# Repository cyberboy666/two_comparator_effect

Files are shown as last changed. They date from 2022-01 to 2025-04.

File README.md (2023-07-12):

# two_comparator_effect
### analog video posterisation effect - adapted from a rob schafer design



- this circuit is distributed by __UNDERSCORES__ - _an open video hardware label_ : it is available to purchase - as a pcb, kit or assembled unit - at [underscores.shop](https://underscores.shop/two_comparator_effect/)
- the schematic for the circuit can be found [here](/hardware/schematic.pdf)
- the pcb gerber files for the lastest version can be found [here](/hardware/gerber_latest.zip)
- interactive BOM is [here](https://htmlpreview.github.io/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)
- consider [donating](https://opencollective.com/underscores) to the underscores project to help us continue creating for the commons

## demo video

(https://videos.scanlines.xyz/w/t1Ht54aVoeiCa2ZGb4LRMV)

## background

<details>
<summary>background</summary>

Rob Schafer designed the original version of this circuit in his excellent [whiteboard schoolhouse](https://www.youtube.com/watch?v=9HMj0sfPa0w&list=PLoNU5z_Oqfgj1xfSBMg6XaIhAX2ftyfkN) youtube series.

It was updated and adapted to pcb by cyberboy666 as open-source hardware with help from the [scanlines community](https://scanlines.xyz/t/whiteboard-schoolhouse-companion-circuits/127/23) – this version debuted as a mail-in soldering workshop for [VIDICON_2020](https://vidicon.org/)







robs original circuit, the schematic and effect shown here 

</details>
  
# documentation

this project is fully _open-source hardware_ - all the files required to build it are included in this repo for free. if you have the time and/or skill you can contribute back by collaborating on / testing new designs, improving these docs, making demo videos/other creative content etc. you can also support the project financially by [donating](https://opencollective.com/underscores) directing, or purchasing through the [web shop](https://underscores.shop).

depending on whether you are going fully diy or buying an assembled and tested unit, some of the following guides will be relavent to you. the flow would be:

## ordering parts

<details><summary><b>parts sourcing guide (w/ notes on pcb fabracation )</b> - start here if you are building fully from scatch or have purchased a pcb</summary>

i try to source all the parts i can from either:
- [tayda](https://www.taydaelectronics.com/) ; cheaper for common parts like resistors etc, also good for mechanical parts like switches and buttons
- [mouser](https://www.mouser.de/) ; has lots more options, speciality video ic's, can sometimes cost more (free shipping on orders over 50euros)
- other ; ocationally there will be parts which will need to be sourced elsewhere - usaully either aliexpress, ebay or amazon etc...

take a look at the [full_bom](/hardware/bom/full_bom.csv) for this project to see where i am sourcing each part from

## import into tayda

- go to the [tayda quick order](https://www.taydaelectronics.com/quick-order/) and in bottom corner choose _add from file_
- select the file [tayda_bom.csv](./hardware/bom/tayda_bom.csv) in the BOM folder (you will have to download it first or clone this repo)
- after importing select _add to cart_
- __NOTE:__ the minimum value for resistors is 10, so you may need to modify these values to add to cart (or if they are already modified here you will need to see the  full_bom for actual part QTY) 

- OPTIONAL: it is a good idea to add some dip-ic sockets and 2.54pin headers/sockets to your tayda order if you dont have them around already
  
## import into mouser

- go to [mouser bom tool](https://nz.mouser.com/Bom/) and click _upload spreadsheet_
- select the file [mouser_bom.csv](./hardware/bom/mouser_bom.csv) in this folder (you will have to download it first or clone this repo), then _upload my spreadsheet_ and _next_
- ensure that __Mouser Part Number__ is selected in the dropdown above the first row, then _next_, _process_
- if everything looks correct can now put _add to basket_

# ordering pcbs

you can support this project by buying individual pcbs from the [shop](https://underscores.shop). if you would rather have pcbs fabricated from gerbers directly the file you need is [here](/hardware/gerber_latest.zip)

- i get my pcbs fabricated from [jlcpcb](https://cart.jlcpcb.com/quote) - 5 is the minumum order per design
- upload the zip file with the `add gerber file` button
- the default settings are mostly fine - set the __PCB Qty__ and __PCB Color__ settings (you can check that the file looks correct with pcb veiwer)
- it may be best to combine orders with other pcbs you want to have fab'd since the shipping can cost more than the items - also orginising group buys is a good way to distribute the extra pcbs /costs 
  
i often use jlcpcb because they are reliable, cheap and give you an option of colours. remember though that the cheapest Chinese fab houses are not always the most ethical or environmently friendly - if you can afford it consider supporting local companies. 

  </details>
  
## assembly guide
  
<details><summary><b>assembly guide</b> - start here if you have purchased a diy kit</summary>

## interactive BOM for build guiding

follow this link to view the [interactive BOM](https://htmlpreview.github.io/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)

## general solder advice

- remember to heat pad first (2-3seconds), then add solder, then continue to heat (1-2seconds)

- Checkout the web-comic [soldering is easy](https://mightyohm.com/files/soldercomic/FullSolderComic_EN.pdf) for more soldering advice

## general order of assembly

- in general while assembling i start placing resistors and capacitors first. placing 5 - 10 components at a time and then flipping the board to solder them and trim the legs etc.
- next i would do diodes, transistors and ic's - taking care that these are placed in the right direction (using a ic socket can be useful)
- finally i place the interface parts - rca jacks, power jack, pots and switches - make sure these have lots of solder on for structural stablity

## specific assembly advice

- start with the resistors, taking care place the correct value in the correct footprint (if you are unsure of the value can use an online resistor calculator ) , direction does not matter. Place a few resistors in (as many as you are comfortable with) then solder and trim legs

- next lets do capacitors: 0.1u will say 104, while 1uf will say 105 on them - place them all and solder and trim.

- now lets place diodes and transistors. take note of the direction on the diode - black bar on component matching black bar on footprint. Transistor values are printed on thembe sure not to mix them up ! be careful when soldering the to92 parts the pads are very close - this is the hardest part - i soldered the outer legs first, trimmed these and then soldered inner.

- now lets do the ic/socket -> make sure the direction is correct! place in and fold two corner pins to hold in place, then solder all pins. you can place the ic in now too.

- finally lets place the control parts, starting with the power jack (can use something under the board to balance it while you solder), next place the rca jacks and pots. be generous with the solder here -> this is to strengthen the mechanical connections as well as making electrical ones
  
</details>

## operating guide
  
<details><summary><b>operating guide</b> - start here if you have purchased an assembled unit</summary>

  

- To set up using the circuit plug an active video source into composite video input and a display into composite video output (flipping the bypass switch should show the raw video source passing through the circuit to the display)

- Next plug in a 5v center-positive power supply into the 2.1mm barrel jack connector – I like to use a usb wall charger for this

- switch the bypass again to activate the circuit - Adjusting the level knobs should change the resulting image – the thresholds control which brightness levels result in white black or gray regions.

- Depending on your display setting either or both knobs fully counter-clockwise can result in glitchy effects, colour bleeds and sync drops

</details>

### more info

<details><summary><b>how the circuit works</b></summary>
  
Watch the youtube videos [Lesson 1 – Comparators](https://www.youtube.com/watch?v=ml8xnRFdcHY) and [Lesson 2 – Clamping](https://www.youtube.com/watch?v=FymrxKLHy6c) by Rob Schafer for full explanation. See full schematics on the project page.
  
This circuit works by using multiple stages of an LM339 - Quad Differential Comparator ic. 


  
A comparator stage compares the two voltages on its input (plus and minus) and outputs high if plus > minus, low if plus < minus. Since we power the ic with +5v, in this case high is an output of +5v and low is an output of 0v
                                                                                                                                 
comparator plus input is connected to the analog video signal (where higher voltage corresponds to a brighter image)


  
The minus input is connected to a reference voltage which can be set by turning a potentiometer. varying the pot adjusts the resistance in this voltage divider configuration which in turn varies the voltage supplied as reference
                                                                                                                                 

The result of this effect is an image that is all white for regions of the original image above a given brightness threshold level, and all black for the regions below this level. Changing this threshold changes which parts of the image are set to black vs white.

Here is a scoped example of an original signal (top) with threshold and the resulting signal (bottom)


                                                                                                                                 
Before reaching the comparators, the incoming video signal needs to be SOFT CLAMPED – this is done using a capacitor, diode and a 1.25v rail that was obtained with a LM317 voltage regulator.



A composite video signal tends to squash up when the image is bright and spread out when it is darker.

For the comparator reference voltages to be consistence we need to correct for this behavior by clamping the signal to a fixed voltage level
                                                                                                                                 


A third comparator stage with a fixed reference voltage is used to ‘pick off’ the sync pulse of the original signal.

The output from these three comparator stages are scaled and combined to create a new composite video signal with the desired effect
                                                                                                                                 


Composite video encodes color as a sub-carrier frequency over the signal.

This circuit is designed for use with gray-scale video input where no sub-carrier is present, although it does still work with color input – usually ignoring the _sub-carrier_, although occasionally there are some artifacts generated by this. This is more common with NTSC than with PAL

glitch artifacts are also created when the comparator thresholds are set below the _black-level_ of the video signal, causing the signal to lose sync. 
                                                                                                                             
</details>

<details><summary><b>contributing guide</b></summary>
  
if you would like to contribute back to these projects in some way but dont know how the best thing (for now) would be to reach out to me directly ( tim@cyberboy666.com or @cyberboy666 on scanlines forum) - i will be happy to help
  
</details>

## credits & more info

This circuit is distributed through UNDERSCORES – open video hardware label – visit [underscores.shop](https://underscores.shop) for more info

The pcb was designed using KICAD , the booklet was created in LibreOffice Draw

Everything from gerbers, cad files, panels and documentation is freely available online and distributed under CC-BY-SA / open-source licenses – help us contribute to the commons !

Ask any questions or start discussions related to this project on the [scanlines.xyz](https://scanlines.xyz) forum – an online community space dedicated to diy av / electronic media art

You can contact me directly at tim (at) cyberboy666 (dot) com 
Please get in touch if you are interested in hosting a workshop !



Thanks to Rob Schafer for sharing your designs and knowledge. to Bastien Lavaud for circuit advice, always. To Guergana Tzatchkova for booklet design inspiration. To Ben Caldwell for project advice. To everyone who has or will contribute ♥♥♥

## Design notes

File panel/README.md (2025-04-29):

# enclosure guide

we now offer two kinds of enclosures for this project:

- __stand-alone enclosure__ - made from a front and back panel, plus screws and standoffs



- __eurorack enclosure__ - made from just a front panel, plus screws and standoffs to mount in a eurorack case



you can support these projects by getting enclosure kits directly through [underscores.shop](https://underscores.shop) - [standalone](https://underscores.shop/product/standalone-enclosure-kit-for-two_comparator_effect/) and [eurorack](https://underscores.shop/product/eurorack-kit-for-two_comparator_effect/) - _if ordered with an assembled unit we will also assemble the enclosure for you also_

# diy part sourcing

## panel fabrication

included in this repo are the cad files needed to create your own panels. they are designed in kicads pcbnew - so open the `.kicad_pcb` file to edit them directly. 

you can also use the exported `gerber` files (here they are combined in `.zip`) to get panels fabricated in __fr4__ at a pcb house like the ones we sell. (these usually have a minimum order of 5 or 10)  

another option for diy fabrication is using a lasercutter to cut the panels in wood or acrylic. this is what i do when prototyping panels so you should find some exports in `svg` or `dxf` that are laser ready. _note that the `edgecut` layer is for cutting out and the `silkscreen` layer is for the panel markings. you may need to edit these files or export directly from pcbnew to suit the cutter you are using_

it would also be possible to import these panel files into a sketch in 3d cad program like __freecad__ to create a 3d enclosure for 3d printing... however this is not something i have files prepared for

## 3d printing

i use some custom modelled switch and pot caps for my enclosure kits. you can print these yourself or upload them to a 3d printing fabrication service.

## enclosure kit BOM

things like screws and standoffs can be sourced from lots of places. i will link my source as an example although these links often expire. you could even 3d print your own standoffs from the _id/od_ and length (inner diameter 3.2mm, outer diameter 5mm)

### standalone enclosure

item | source
--- | ---
Front panel | [two_comparator_effect_v0_3_1_default_panel_mk_ii.zip](https://github.com/cyberboy666/two_comparator_effect/blob/main/panel/default_panel/two_comparator_effect_v0_3_1_default_panel_mk_ii.zip) gerber
Back panel | [back_panel.zip](https://github.com/cyberboy666/two_comparator_effect/blob/main/panel/back_panel/back_panel.zip)
Rubber feet x4 | [aliexpress](https://www.aliexpress.com/item/1005005287385986.html?pdp_ext_f=%7B%22sku_id%22:%2212000032498489269%22%7D)
Pot cap x2 | 3d printed from [stl file](https://github.com/cyberboy666/enclosure_kit_commons/blob/main/cap_pot_6mm_shaft/cap_pot_star_single_r2.8.stl)
M3-25mm screw x4 | [aliexpress](https://www.aliexpress.com/item/1005002364189187.html?pdp_ext_f=%7B%22sku_id%22:%2212000020354274907%22%7D)
M3 nut x4 | [aliexpress](https://www.aliexpress.com/item/1005007502691265.html?pdp_ext_f=%7B"sku_id":"12000041089836836"%7D)
m3-12mm standoff x4 (front) | [aliexpress](https://www.aliexpress.com/item/1005003086579258.html?pdp_ext_f=%7B"sku_id":"12000023995222163"%7D)
m3-5mm standoff x4 (back) | [aliexpress](https://www.aliexpress.com/item/1005003086579258.html?pdp_ext_f=%7B"sku_id":"12000023995222156"%7D)

### eurorack enclosure

item | source
--- | ---
Eurorack front panel | [two_comparator_effect_panel_v0_3_1_eurorack_panel_mk_ii.zip](https://github.com/cyberboy666/two_comparator_effect/blob/main/panel/eurorack_panel/two_comparator_effect_panel_v0_3_1_eurorack_panel_mk_ii.zip)
Eurorack 16pin power converter | [eurorack_to_usb_passive_mk_i.zip](https://github.com/cyberboy666/enclosure_kit_commons/blob/main/eurorack_power-adapters/eurorack_to_usb_passive/eurorack_to_usb_passive_mk_i.zip) gerber
Vertical barrel jack | [tayda](https://www.taydaelectronics.com/dc-power-jack-2-1mm-round-type-panel-mount-1.html)
Pot cap x2 | 3d printed from [stl file](https://github.com/cyberboy666/enclosure_kit_commons/blob/main/cap_pot_6mm_shaft/cap_pot_star_single_r2.8.stl)
M3-25mm screw x4 | [aliexpress](https://www.aliexpress.com/item/1005002364189187.html?pdp_ext_f=%7B%22sku_id%22:%2212000020354274907%22%7D)
M3 nut x4 | [aliexpress](https://www.aliexpress.com/item/1005007502691265.html?pdp_ext_f=%7B"sku_id":"12000041089836836"%7D)
m3-12mm standoff x4 (front) | [aliexpress](https://www.aliexpress.com/item/1005003086579258.html?pdp_ext_f=%7B"sku_id":"12000023995222163"%7D)
m3-8mm screw x4 | [aliexpress](https://www.aliexpress.com/item/1005002364189187.html?pdp_ext_f=%7B%22sku_id%22:%2212000020354274900%22%7D)

## eurorack power jack placement

many underscores circuits take 5v from a [horizontal mounted dc barrel jack](https://www.taydaelectronics.com/dc-power-jack-2-1mm-barrel-type-pcb-mount.html) which is good for standalone circuits powered from the side. however for eurorack mounted circuits it can be easier to plug in power from behind. in this case we can use a [vertical dc socket](https://www.taydaelectronics.com/dc-power-jack-2-1mm-round-type-panel-mount-1.html) instead. for these sockets the longer pin is GND which goes closest to the edge of pcb.

Screenshot from 2025-04-29 11-19-55



## enclosure assembling

these enclosures are assemlbed by creating a stack of front-panel -> circuit -> back-panel using the screws and standoffs. where the front standoffs go between front panel and pcb and back standoff go between back panel and pcb. the m3 hex holds it together from the bottom.

i find it easiest to hold circuit on its side and work around one screw at a time:

- first place the front standoff between front panel and pcb
- then put the screw through holding them together
- next place back standoff on screw followed by back panel and hex
- then repeat for other 3 corners

tweezers can be helpful to pick and place the standoffs and also to tighten the m3 hexs

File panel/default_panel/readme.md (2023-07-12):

# two_comparator_effect default_panel notes

- the mounting holes fit m3 screws
- the front_panel mounts to pcb with 12mm standoffs
- 25mm screws will fit front_panel, pcb and back_plate
- the default potentiometers in underscores BOMs have 12mm shaft lengths - consider replacing these with >17mm shaft length alternatives if you plan to use it with a panel

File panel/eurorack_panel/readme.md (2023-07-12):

# two_comparator_effect eurorack_panel notes

- the mounting holes fit m3 screws
- the front_panel mounts to pcb with 12mm standoffs
- this circuit is powered by 5v on 2.1_barrel_jack - a [vertical jack](https://www.taydaelectronics.com/dc-power-jack-2-1mm-round-type-panel-mount-1.html) soldered to bottom of pcb will allow powering from within eurorack case
- this panel is 7HP
- the default potentiometers in underscores BOMs have 12mm shaft lengths - consider replacing these with >17mm shaft length alternatives if you plan to use it with a panel

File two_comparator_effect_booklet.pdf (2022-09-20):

### cyberboy666 & underscores.shop present a circuit adapted from rob schafer design

# two_comparator_effect

## diy analog video posterization

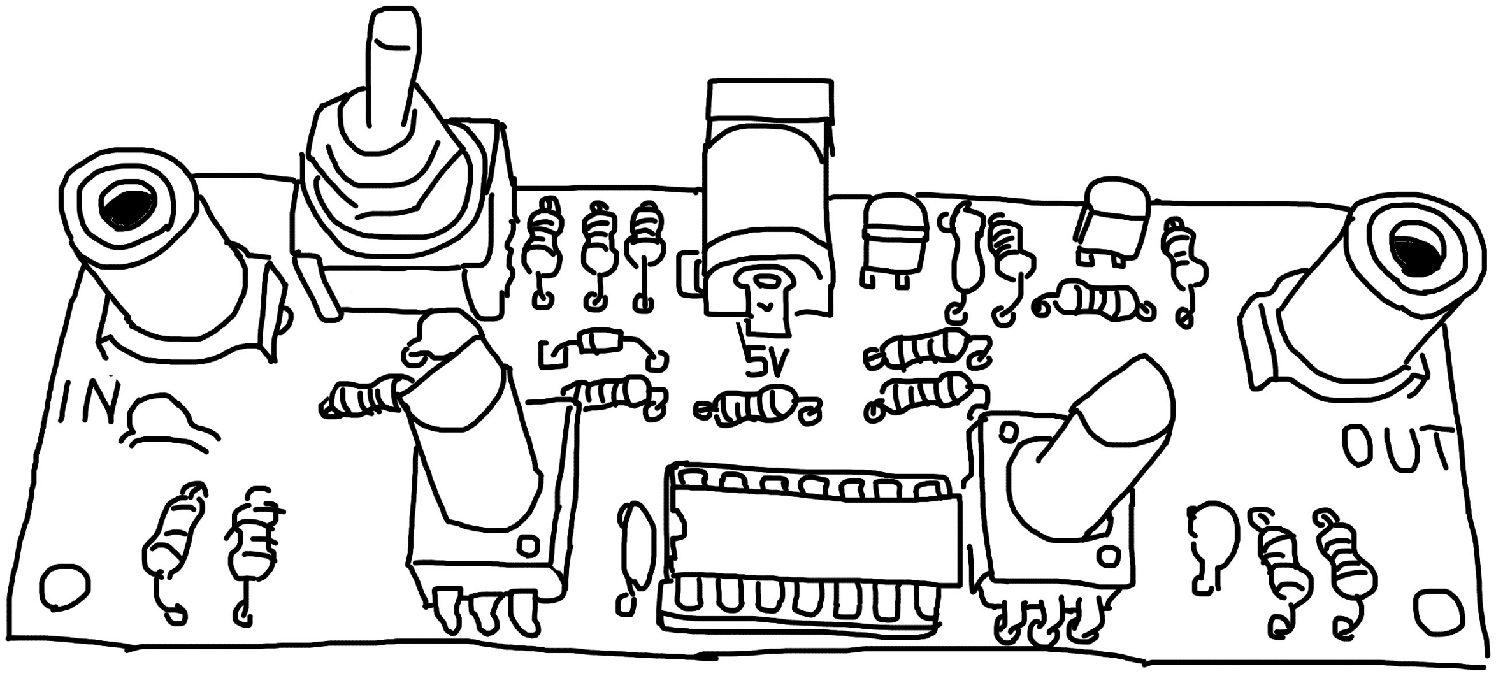
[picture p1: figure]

## instruction manual and build guide

## V0_3_1

View this project online at underscores.shop/two_comparator_effect

# BACKGROUND

### VIDICON_2020

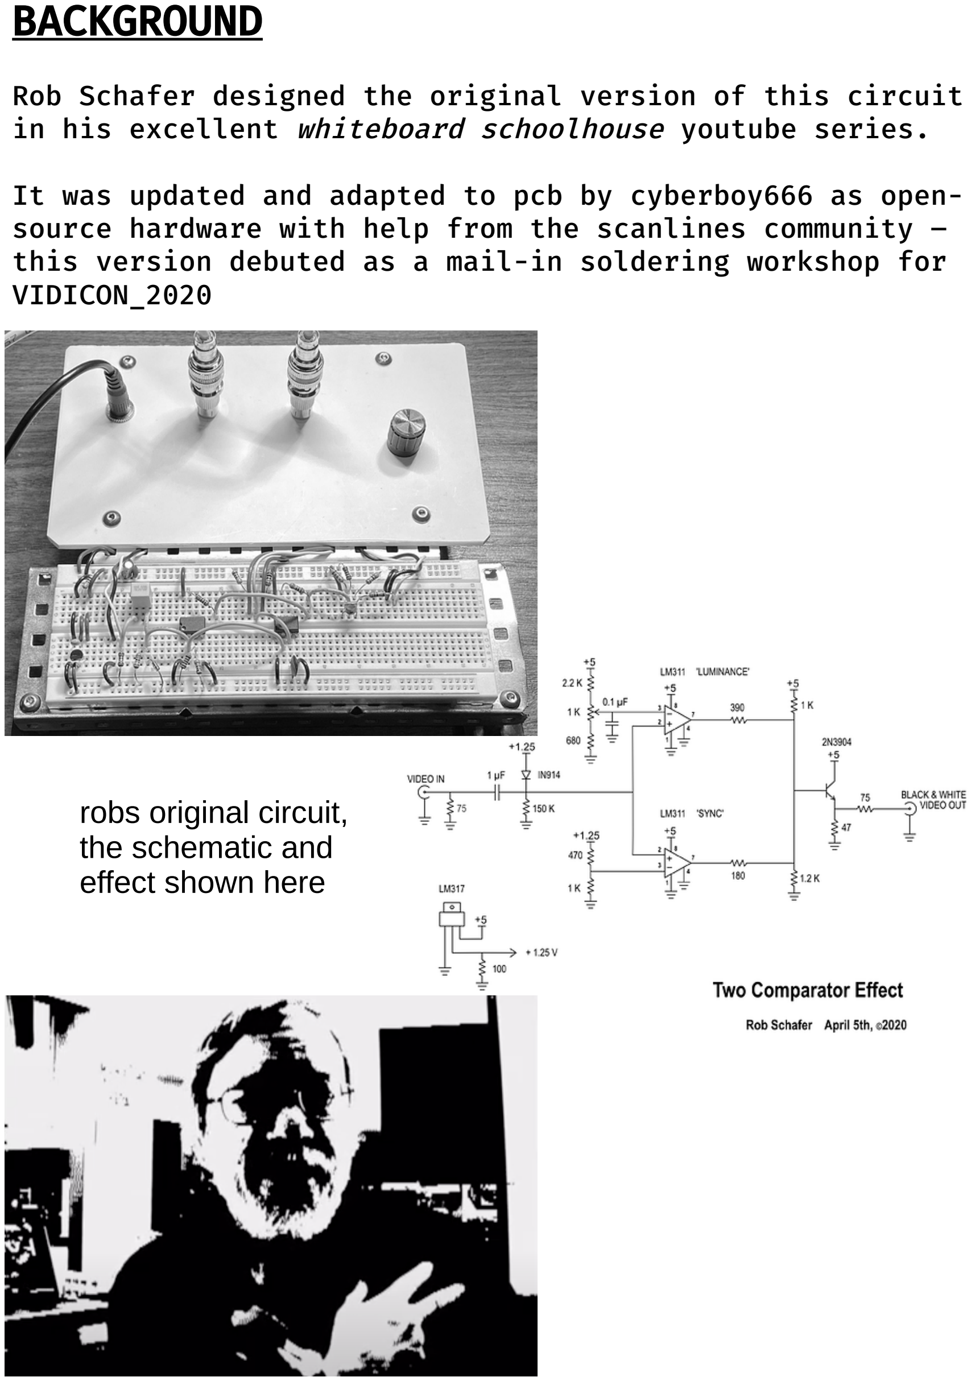
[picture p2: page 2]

Rob Schafer designed the original version of this circuit in his excellent whiteboard schoolhouse youtube series.

It was updated and adapted to pcb by cyberboy666 as open-source hardware with help from the scanlines community – this version debuted as a mail-in soldering workshop for

robs original circuit,
the schematic and
effect shown here

Quantity | Reference | Value
3 | C3 C2 C1 | 1u
1 | C4 | 0.1u
1 | D1 | 1n914
2 | J2 J1 | rca
1 | J3 | Barrel_Jack
1 | Q1 | 2N3904
1 | R11 | 47
1 | R12 | 470
1 | R13 | 180
1 | R14 | 1.5k
2 | R15 R2 | 1k
1 | R16 | 100
2 | R5 R1 | 3k
1 | R6 | 680
1 | R7 | 1.2k
2 | R4 R3 | 910
2 | R8 R10 | 75
1 | R9 | 150k
2 | RV2 RV1 | 1k_pot
1 | U1 | LM339
1 | U2 | LM317
2 | J1, J2 | rca

# BILL OF MATERIAL

It is highly recommended to use the interactive BOM to help with placement on this build – type kutt.it/cTyEze into a browser or find the links from the github page

# BUILD INSTRUCTIONS

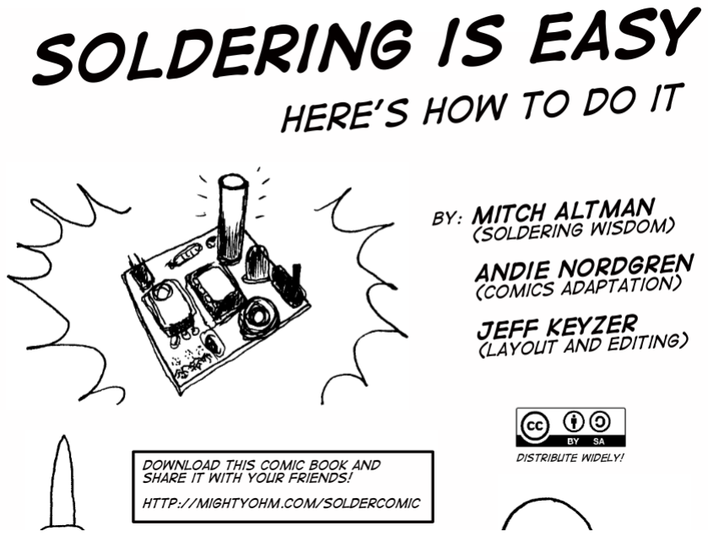
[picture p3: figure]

- start with the resistors, taking care place the correct value in the correct footprint (if you are unsure of the value can use an online resistor calculator ) , direction does not matter. Place a few resistors in (as many as you are comfortable with) then solder and trim legs
- next lets do capacitors: 0.1u will say 104, while 1uf will say 105 on them - place them all and solder and trim.
- now lets place diodes and transistors. take note of the direction on the diode - black bar on component matching black bar on footprint. Transistor values are printed on thembe sure not to mix them up ! be careful when soldering the to92 parts the pads are very close - this is the hardest part - i soldered the outer legs first, trimmed these and then soldered inner.
- now lets do the ic/socket -> make sure the direction is correct! place in and fold two corner pins to hold in place, then solder all pins. you can place the ic in now too.
- finally lets place the control parts, starting with the power jack (can use something under the board to balance it while you solder), next place the rca jacks and pots. be generous with the solder here -> this is to strengthen the mechanical connections as well as making electrical ones

See operating instructions page for setup and testing

note on soldering: remember to heat pad first (2-
3seconds), then add solder, then continue to heat (1-
2seconds)

Checkout the web-comic
soldering is easy for more soldering advice

# OPERATING INSTRUCTIONS

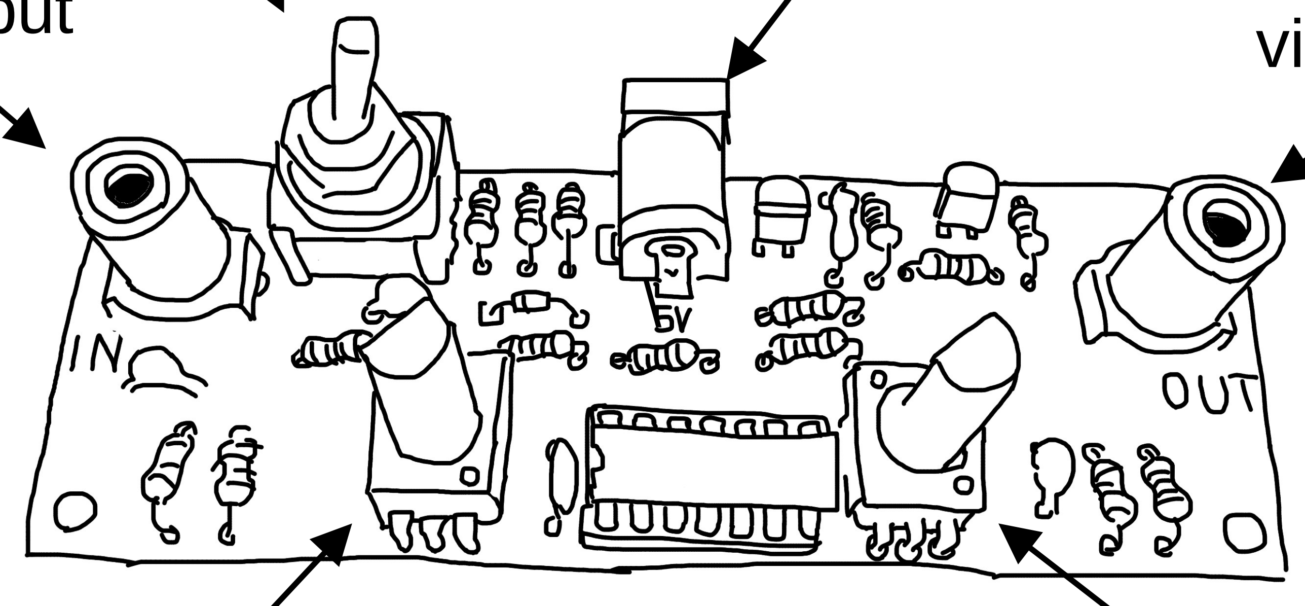
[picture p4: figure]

To set up using the circuit plug an active video source into composite video input and a display into composite video output (test input/outputs by toggling signal bypass switch first to ensure they are working as expected)

Next plug in a 5v center-positive power supply into the 2.1mm barrel jack connector – I like to use a usb wall charger for this – and toggle off the bypass

Adjusting the level knobs should change the resulting image – the thresholds control which brightness levels result in white black or gray regions.

composite
video input | composite
| video output

5v power input

(2.1mm barrel center positive)

comparator 1
threshold level

comparator 2
threshold level

signal
bypass

# HOW THE CIRCUIT WORKS

Watch the youtube videos Lesson 1 – Comparators and Lesson 2 – Clamping by Rob Schafer for full explanation. See full schematics on the project page.

This circuit works by using multiple
stages of an LM339 - Quad Differential
Comparator ic.

A comparator stage compares the two voltages on its input (plus and minus) and outputs high if plus > minus, low if plus < minus. Since we power the ic with +5v, in this case high is an output of +5v and low is an output of 0v

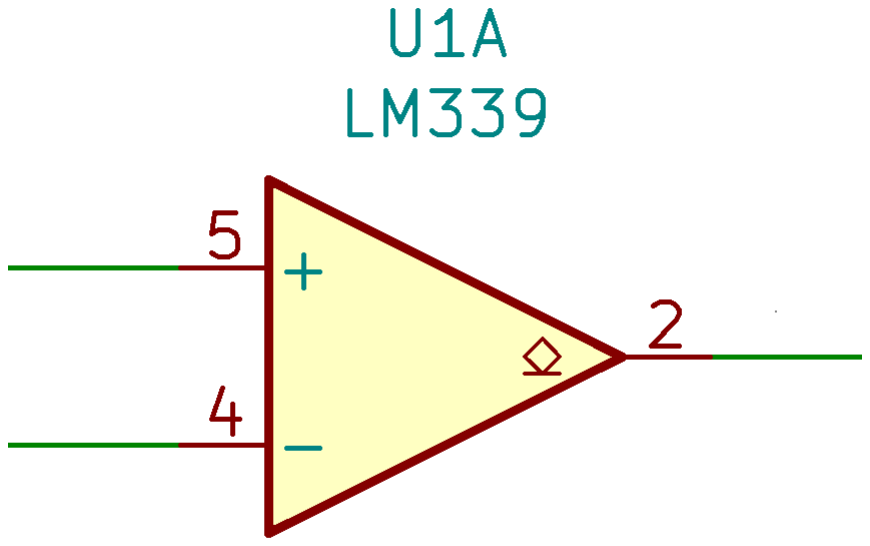
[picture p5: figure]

comparator plus input is connected to the analog video signal (where higher voltage corresponds to a brighter image)

The minus input is connected to a reference voltage which can be set by turning a potentiometer. varying the pot adjusts the resistance in this voltage divider configuration which in turn varies the voltage supplied as reference

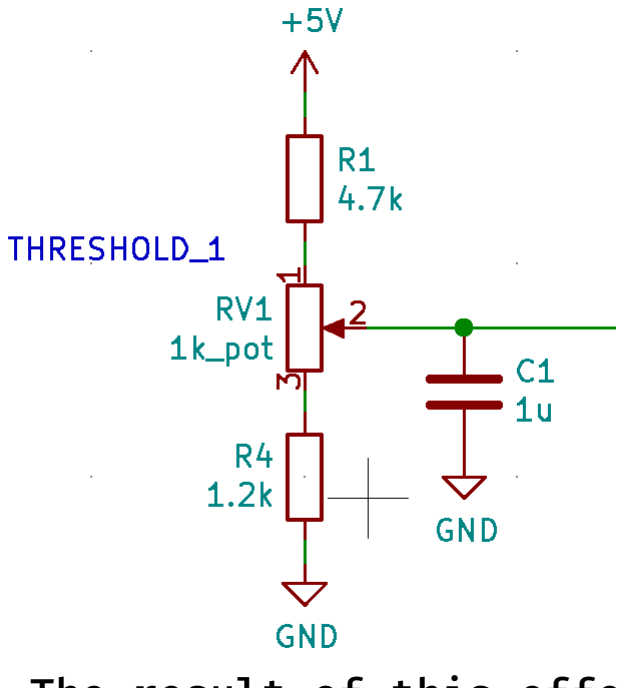
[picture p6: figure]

The result of this effect is an image that is all white for regions of the original image above a given brightness threshold level, and all black for the regions below this level. Changing this threshold changes which parts of the image are set to black vs white.

Here is a scoped example of an original signal (top) with threshold and the resulting signal (bottom)

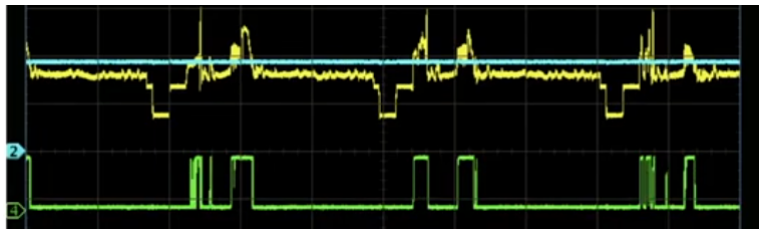
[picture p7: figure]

# HOW THE CIRCUIT WORKS CONTINUED

Before reaching the comparators, the incoming video signal needs to be SOFT CLAMPED – this is done using a capacitor, diode and a 1.25v rail that was obtained with a LM317 voltage regulator.

A composite video signal tends to squash up when the image is bright and spread out when it is darker.

For the comparator reference voltages to be consistence we need to correct for this
behavior by clamping the signal to a fixed voltage level

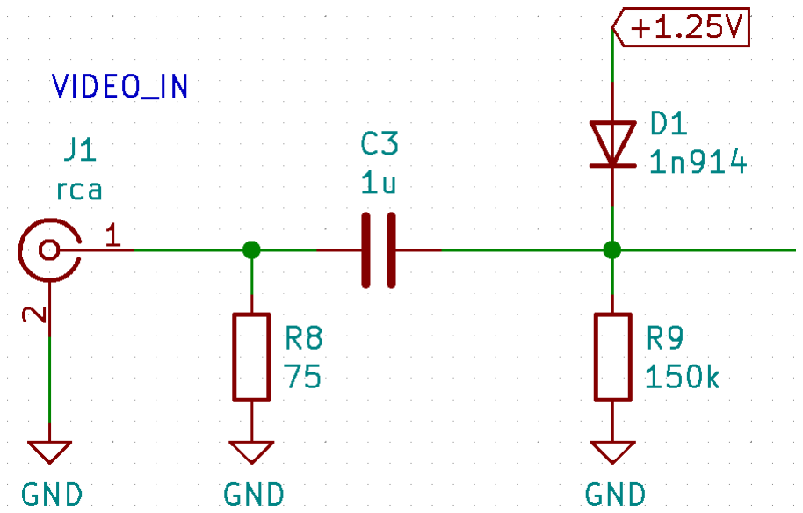
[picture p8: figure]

A third comparator stage with a fixed reference voltage is used to ‘pick off’ the sync pulse of the original signal.

The output from these three comparator stages are scaled and combined to create a new composite video signal with the desired effect

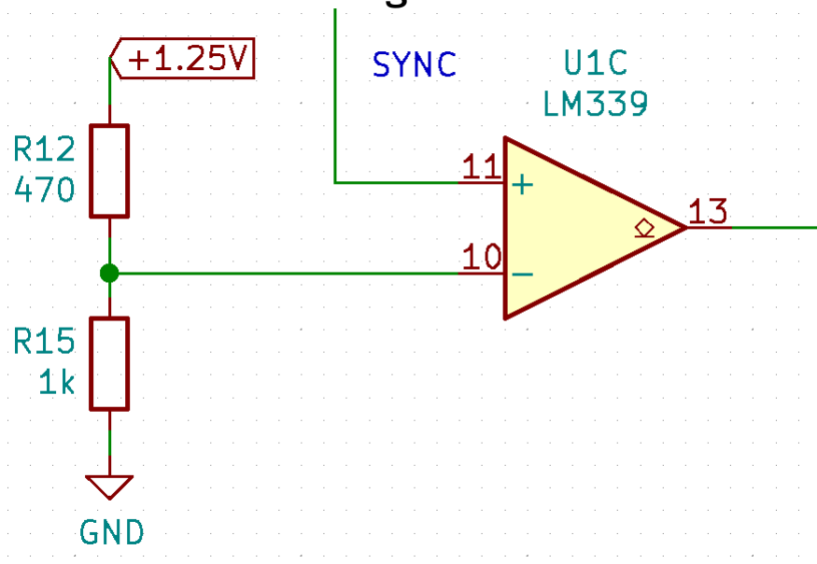
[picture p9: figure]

Composite video encodes color as a sub-carrier frequency over the signal.

This circuit is designed for use with gray-scale video input where no sub-carrier is
present, although it does still work with color input – usually ignoring the sub-carrier,
although occasionally there are some artifacts generated by this. This is more common with NTSC than with PAL

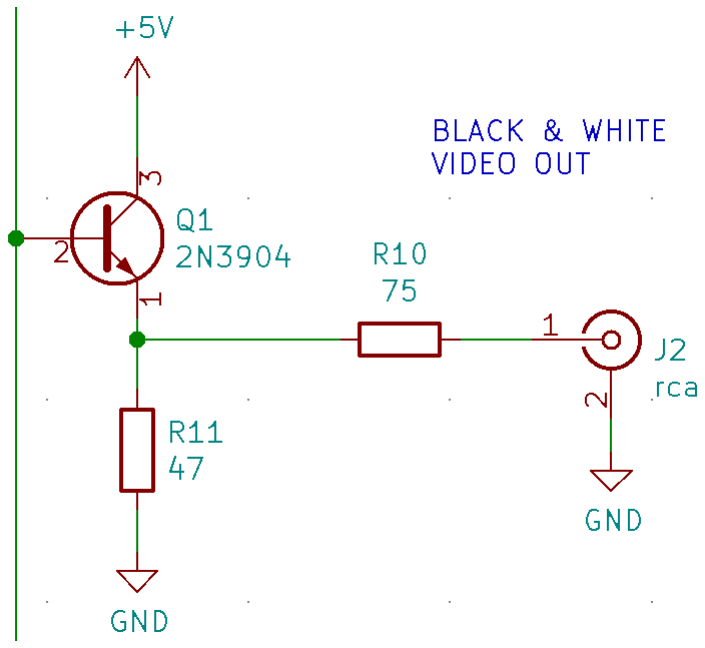
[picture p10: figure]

glitch artifacts are also created when the comparator thresholds are set below the black-level of the video signal, causing the signal to lose sync.

# CREDITS AND MORE INFO

This circuit is distributed through UNDERSCORES – open video hardware label – visit underscores.shop for more info

The pcb was designed using KICAD , this booklet was created in LibreOffice Draw

Everything from gerbers, cad files, panels and documentation is freely available online and distributed under CC-BY-SA / open-source licenses – help us contribute to the commons !

Ask any questions or start discussions related to this project on the scanlines.xyz forum – an online community space dedicated to diy av / electronic media art

You can contact me directly at tim (at) cyberboy666 (dot) com Please get in touch if you are interested in hosting a
workshop !

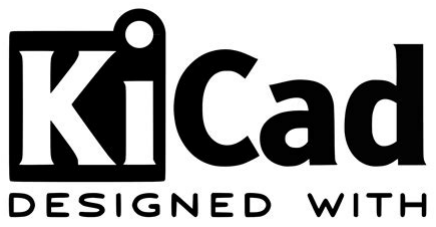
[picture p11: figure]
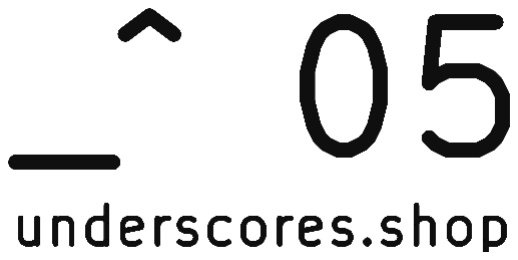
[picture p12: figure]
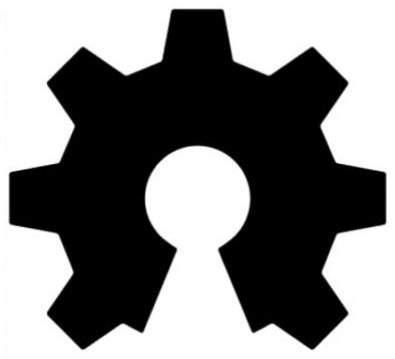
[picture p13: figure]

Thanks to Rob Schafer for sharing your designs and knowledge. to Bastien Lavaud for circuit advice, always. To Guergana Tzatchkova for booklet design inspiration. To Ben Caldwell for project advice. To everyone who has or will contribute ♥♥♥

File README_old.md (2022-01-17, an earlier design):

# two_comparator_effect

### analog video posterisation effect - adapted from a rob schafer design 



## lessons

this circuit is based on one described by Rob Schafer in:

- [Lesson 1 - Comparators](https://www.youtube.com/watch?v=ml8xnRFdcHY)
- [Lesson 2 - Clamping](https://www.youtube.com/watch?v=FymrxKLHy6c)

also see: [original schematic](https://www.youtube.com/watch?v=MSNrXUDO9DE) and [clamping scope example](https://www.youtube.com/watch?v=vQ15EZKisZ8)



## adaption

see this [scanlines thread](https://scanlines.xyz/t/whiteboard-schoolhouse-companion-circuits/127) for discussion on this project

video demos from this adaption:

- [2comparatorFx+recurboy](https://videos.scanlines.xyz/videos/watch/49ce42f5-12a4-4f6e-85ff-bbef453d9e1e)
- [2comparatorFx+recurboy_p2](https://videos.scanlines.xyz/videos/watch/e029e6a6-3494-4a65-8555-49e3c94d06a6)

# v0.2 bom:

## [interactive bom](https://htmlpreview.github.io/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)

Qty | Reference(s) | Value | tayda | mouser
--- | --- | --- | --- | ---
3 | C1, C2, C3 | 1u | A-321 | -
1 | C4 | 0.1u | A-214 | -
1 | D1 | 1n914 | A-615 | -
2 | J1, J2 | RCA | - | 490-RCJ-024
1 | J3 | Barrel_Jack | A-4118 | -
1 | Q1 | 2N3904 | A-111 | -
2 | R1, R5 | 4.7k | A-2310 | -
2 | R2, R15 | 1k | A-2200 | -
3 | R3, R4, R7 | 1.2k | A-2201 | -
1 | R6 | 680 | A-2281 | -
2 | R8, R10 | 75 | A-2193 | -
1 | R9 | 150k | A-2210 | -
1 | R11 | 47 | A-2190 | -
1 | R12 | 470 | A-2247 | -
1 | R13 | 180 | A-2278 | -
1 | R14 | 1.5k | A-2202 | -
1 | R16 | 100 | A-2245 | -
2 | RV1, RV2 | 1k | - | 652-PTV09A-4225FB102
1 | U1 | LM339 | A-022 | -
1 | U2 | LM317 | A-500 | -
1 | - | 14pin socket | A-004 | -

# build instructions:

what you need:

- soldering iron
- solder
- tin/sponge
- wire clippers
- cvbs video source
- cvbs video display
- 5v barrel plug powersupply (either to wall or to usb)

maybe useful: 

- solder braid/pump
- multi meter

## building

- note on soldering: try to remember to heat pad first (2-3seconds), then add solder, then continue to heat (1-2seconds)

- start with the resistors, taking care place the correct value resisitor in the correct footprint (if you are unsure of the value can use [this](http://resistor.cherryjourney.pt/) calculator ) , direction does not matter. lets try placing half the resistors first (up to r6) then soldering and trimming , then placing the second half

- next lets do capicitors: will need to idenitfy which is 0.1u (will say 104, while the others say 105 on it), then place them all and solder and trim.

- now lets place diodes and transistors. _take note of the direction on the diode_ - black bar on component matching black bar on footprint. also you need to read the transistors to tell which is which - they are not the same ! be careful when soldering the to92 parts the pads are very close - this is the hardest part ! (i soldered the outer legs first, trimmed these and then soldered inner)

- now lets do the ic socket -> _make sure the direction is correct!_ place in and fold two corner legs to hold in place, then solder all legs. you can place the ic in now too

- finally lets place the control parts, starting with the power jack (can use something under teh board to balance it while you solder), next place the rca jacks and pots. be generous with the solder here -> this is to strengthen the mechanical connections aswell as making electrical ones

## testing

and the circuit is done ! check for any solder bridges or unsoldered joins - use a multimeter to be sure if you have one. time to test. best to start by setting up your cvbs video source and plugging directly into the cvbs video display -> is this giving the expected image ?

next power the device (no funny smells?) , and try patching the cvbs source through the two_comparator_effect -> anything on the screen ? try adjusting the knobs - at the lower end might drop out..

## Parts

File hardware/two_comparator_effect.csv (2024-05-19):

Reference | Quantity | Value | Footprint | Datasheet
C1 C2 C3 | 3 | 1u | Capacitor_THT:C_Disc_D4.7mm_W2.5mm_P5.00mm
C4 | 1 | 0.1u | Capacitor_THT:C_Disc_D4.7mm_W2.5mm_P5.00mm
D1 | 1 | 1n914 | Diode_THT:D_A-405_P7.62mm_Horizontal
J1 J2 | 2 | rca | lib:tht_rca_vertical | ~
J3 | 1 | Barrel_Jack | Connector_BarrelJack:BarrelJack_Horizontal
Q1 | 1 | 2N3904 | Package_TO_SOT_THT:TO-92_HandSolder | https://www.fairchildsemi.com/datasheets/2N/2N3904.pdf
R1 R5 | 2 | 3k | Resistor_THT:R_Axial_DIN0207_L6.3mm_D2.5mm_P7.62mm_Horizontal
R11 | 1 | 47 | Resistor_THT:R_Axial_DIN0207_L6.3mm_D2.5mm_P7.62mm_Horizontal
R12 | 1 | 470 | Resistor_THT:R_Axial_DIN0207_L6.3mm_D2.5mm_P7.62mm_Horizontal
R13 | 1 | 180 | Resistor_THT:R_Axial_DIN0207_L6.3mm_D2.5mm_P7.62mm_Horizontal
R14 | 1 | 1.5k | Resistor_THT:R_Axial_DIN0207_L6.3mm_D2.5mm_P7.62mm_Horizontal
R16 | 1 | 100 | Resistor_THT:R_Axial_DIN0207_L6.3mm_D2.5mm_P7.62mm_Horizontal
R2 R15 | 2 | 1k | Resistor_THT:R_Axial_DIN0207_L6.3mm_D2.5mm_P7.62mm_Horizontal
R3 | 1 | 1.2k | Resistor_THT:R_Axial_DIN0207_L6.3mm_D2.5mm_P7.62mm_Horizontal
R4 R7 | 2 | 910 | Resistor_THT:R_Axial_DIN0207_L6.3mm_D2.5mm_P7.62mm_Horizontal
R6 | 1 | 680 | Resistor_THT:R_Axial_DIN0207_L6.3mm_D2.5mm_P7.62mm_Horizontal
R8 R10 | 2 | 75 | Resistor_THT:R_Axial_DIN0207_L6.3mm_D2.5mm_P7.62mm_Horizontal
R9 | 1 | 150k | Resistor_THT:R_Axial_DIN0207_L6.3mm_D2.5mm_P7.62mm_Horizontal
RV1 RV2 | 2 | 1k_pot | lib:Potentiometer_Vertical_Large
SW1 | 1 | SW_DPDT_x2 | lib:dpdt_mini_toggle_switch_tayda
U1 | 1 | LM339 | Package_DIP:DIP-14_W7.62mm_LongPads | http://www.ti.com/lit/ds/symlink/lm339.pdf
U2 | 1 | LM317 | Package_TO_SOT_THT:TO-92_Inline | http://www.ti.com/lit/ds/snvs775k/snvs775k.pdf

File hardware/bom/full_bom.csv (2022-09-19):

sku | qty | ref | val | vendor
A-321 | 3 | C1 C2 C3 | 1u | tayda
A-4008 | 1 | C4 | 0.1u | tayda
A-615 | 1 | D1 | 1n914 | tayda
490-RCJ-024 | 2 | J1 J2 | rca | mouser
A-4118 | 1 | J3 | Barrel_Jack | tayda
A-111 | 1 | Q1 | 2N3904 | tayda
A-2349 | 2 | R1 R5 | 3k | tayda
A-2190 | 1 | R11 | 47 | tayda
A-2247 | 1 | R12 | 470 | tayda
A-2278 | 1 | R13 | 180 | tayda
A-2202 | 1 | R14 | 1.5k | tayda
A-2245 | 1 | R16 | 100 | tayda
A-2200 | 2 | R2 R15 | 1k | tayda
A-2201 | 1 | R3 | 1.2k | tayda
A-2623 | 2 | R4 R7 | 910 | tayda
A-2281 | 1 | R6 | 680 | tayda
A-2193 | 2 | R8 R10 | 75 | tayda
A-2210 | 1 | R9 | 150k | tayda
A-1863 | 2 | RV1 RV2 | 1k_pot | tayda
A-4568 | 1 | SW1 | SW_DPDT_x2 | tayda
A-022 | 1 | U1 | LM339 | tayda
A-500 | 1 | U2 | LM317 | tayda

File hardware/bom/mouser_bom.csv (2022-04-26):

sku | qty | ref | val | vendor
490-RCJ-024 | 2 | J1 J2 | rca | mouser

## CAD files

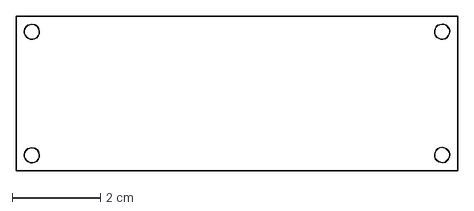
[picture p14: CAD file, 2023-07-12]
panel/back_panel/back_panel-Edge_Cuts.dxf
10.0 x 3.50 cm

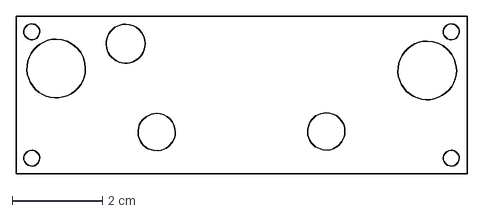
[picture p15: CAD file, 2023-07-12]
panel/default_panel/two_comparator_effect_panel-Edge_Cuts.dxf
10.0 x 3.50 cm

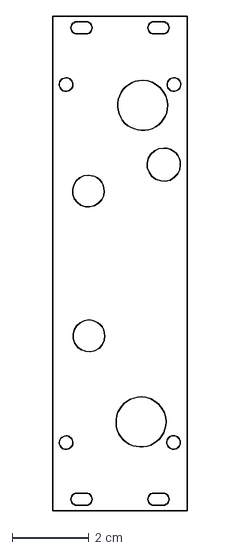
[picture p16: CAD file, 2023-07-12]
panel/eurorack_panel/two_comparator_effect_panel-Edge_Cuts.dxf
3.50 x 12.8 cm

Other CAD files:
panel/default_panel/two_comparator_effect_panel-F_Silkscreen.dxf
panel/eurorack_panel/two_comparator_effect_panel-F_Silkscreen.dxf

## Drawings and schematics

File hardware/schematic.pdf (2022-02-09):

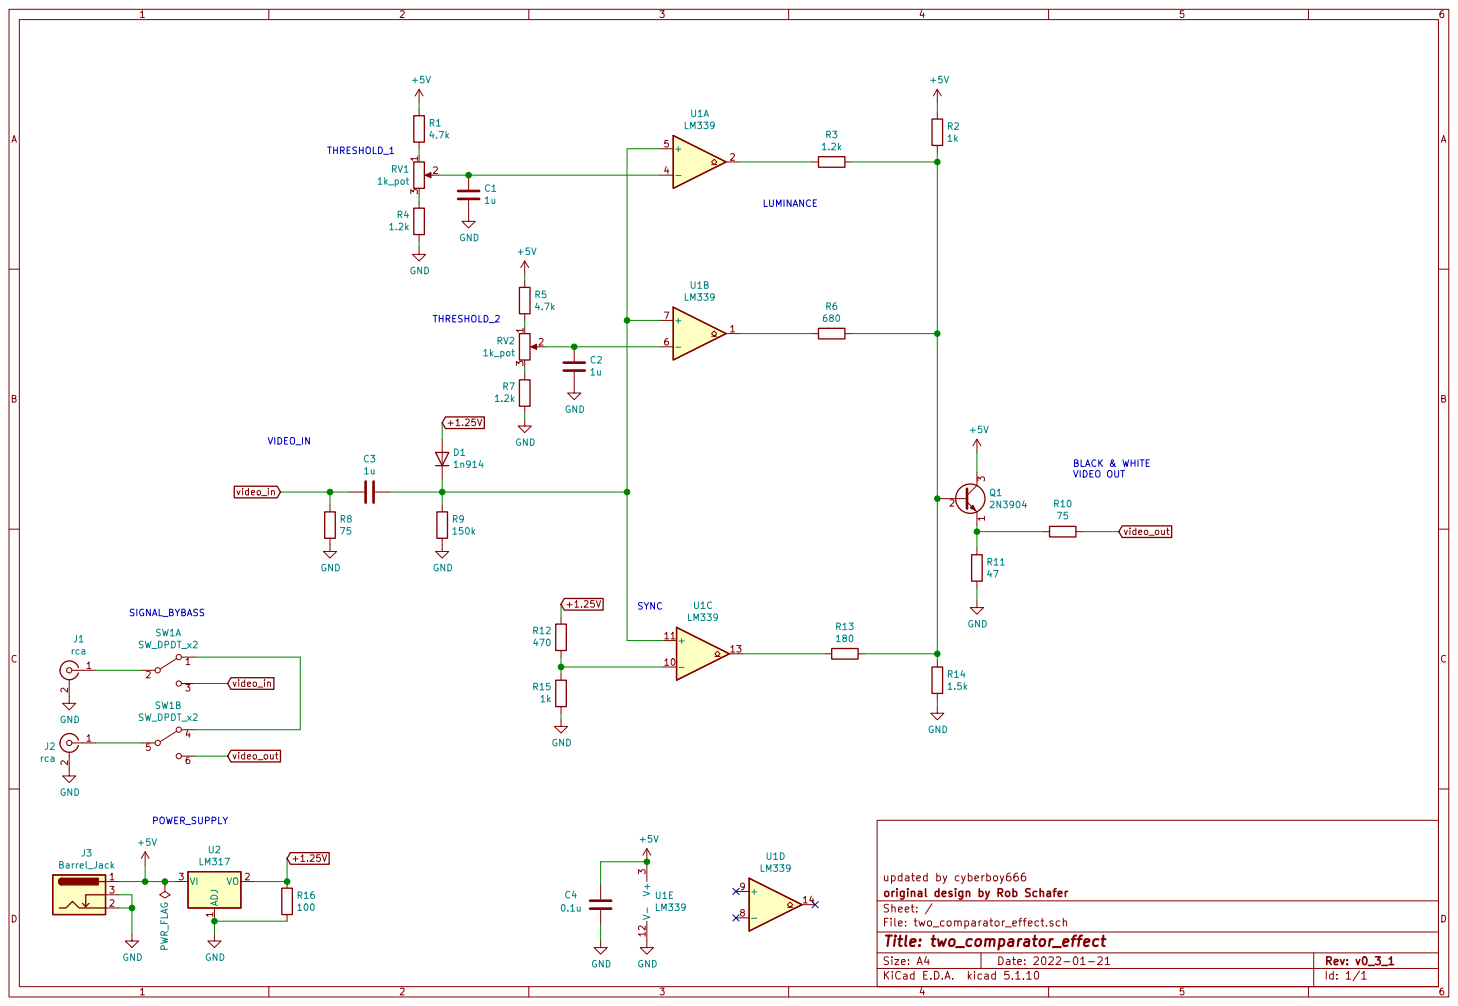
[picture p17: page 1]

BLACK & WHITE VIDEO OUT POWER_SUPPLY

File: two_comparator_effect.sch Sheet: / original design by Rob Schafer

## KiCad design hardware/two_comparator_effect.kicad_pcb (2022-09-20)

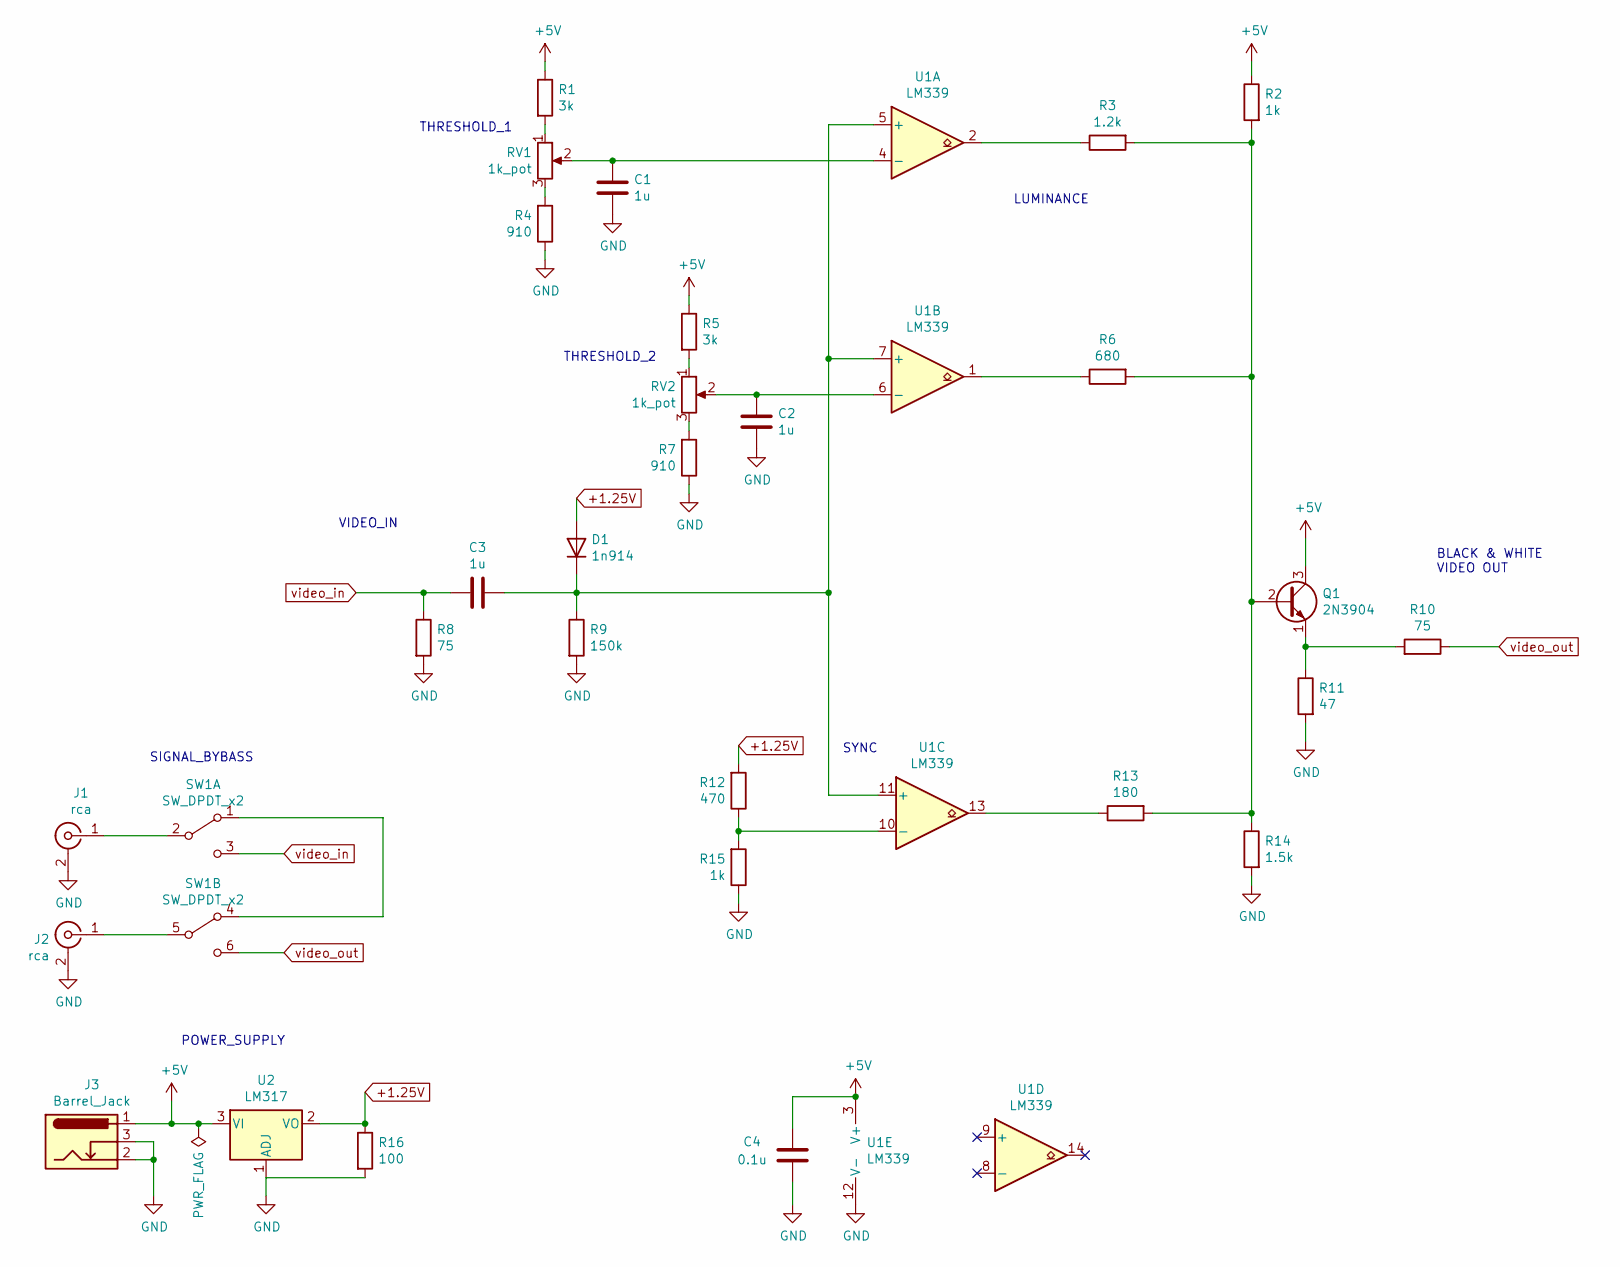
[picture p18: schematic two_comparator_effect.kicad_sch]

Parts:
C1, C2, C3: 1u; C_Disc_D4.7mm_W2.5mm_P5.00mm
C4: 0.1u; C_Disc_D4.7mm_W2.5mm_P5.00mm
D1: 1n914; D_A-405_P7.62mm_Horizontal
J1, J2: rca; tht_rca_vertical
J3: Barrel_Jack; BarrelJack_Horizontal
Q1: 2N3904; TO-92_HandSolder
R1, R5: 3k; R_Axial_DIN0207_L6.3mm_D2.5mm_P7.62mm_Horizontal
R2, R15: 1k; R_Axial_DIN0207_L6.3mm_D2.5mm_P7.62mm_Horizontal
R3: 1.2k; R_Axial_DIN0207_L6.3mm_D2.5mm_P7.62mm_Horizontal
R4, R7: 910; R_Axial_DIN0207_L6.3mm_D2.5mm_P7.62mm_Horizontal
R6: 680; R_Axial_DIN0207_L6.3mm_D2.5mm_P7.62mm_Horizontal
R8, R10: 75; R_Axial_DIN0207_L6.3mm_D2.5mm_P7.62mm_Horizontal
R9: 150k; R_Axial_DIN0207_L6.3mm_D2.5mm_P7.62mm_Horizontal
R11: 47; R_Axial_DIN0207_L6.3mm_D2.5mm_P7.62mm_Horizontal
R12: 470; R_Axial_DIN0207_L6.3mm_D2.5mm_P7.62mm_Horizontal
R13: 180; R_Axial_DIN0207_L6.3mm_D2.5mm_P7.62mm_Horizontal
R14: 1.5k; R_Axial_DIN0207_L6.3mm_D2.5mm_P7.62mm_Horizontal
R16: 100; R_Axial_DIN0207_L6.3mm_D2.5mm_P7.62mm_Horizontal
RV1, RV2: 1k_pot; Potentiometer_Vertical_Large
SW1: SW_DPDT_x2; dpdt_mini_toggle_switch_tayda
U1: LM339; DIP-14_W7.62mm_LongPads
U2: LM317; TO-92_Inline

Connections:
+1.25V: D1.2 (A), R12.2, R16.1, U2.2 (VO)
+5V: C4.1, J3.1, Q1.3 (C), R1.1, R2.1, R5.1, U1.3 (V+), U2.3 (VI)
GND: C1.1, C2.1, C4.2, J1.2 (Ext), J2.2 (Ext), J3.2, J3.3, R4.1, R7.1, R8.2, R9.2, R11.2, R14.2, R15.1, R16.2, U1.12 (V-), U2.1 (ADJ)
unnamed: C1.2, RV1.2, U1.4 (-)
unnamed: C2.2, RV2.2, U1.6 (-)
unnamed: C3.1, D1.1 (K), R9.1, U1.5 (+), U1.7 (+), U1.11 (+)
unnamed: J1.1 (In), SW1.2 (B)
unnamed: J2.1 (In), SW1.5 (B)
unnamed: Q1.1 (E), R10.2, R11.1
unnamed: Q1.2 (B), R2.2, R3.2, R6.2, R13.2, R14.1
unnamed: R1.2, RV1.1
unnamed: R3.1, U1.2
unnamed: R4.2, RV1.3
unnamed: R5.2, RV2.1
unnamed: R6.1, U1.1
unnamed: R7.2, RV2.3
unnamed: R12.1, R15.2, U1.10 (-)
unnamed: R13.1, U1.13
unnamed: SW1.1 (A), SW1.4 (A)
video_in: C3.2, R8.1, SW1.3 (C)
video_out: R10.1, SW1.6 (C)

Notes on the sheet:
THRESHOLD_2
BLACK & WHITE VIDEO OUT
POWER_SUPPLY
THRESHOLD_1
SYNC
VIDEO_IN
SIGNAL_BYBASS
LUMINANCE

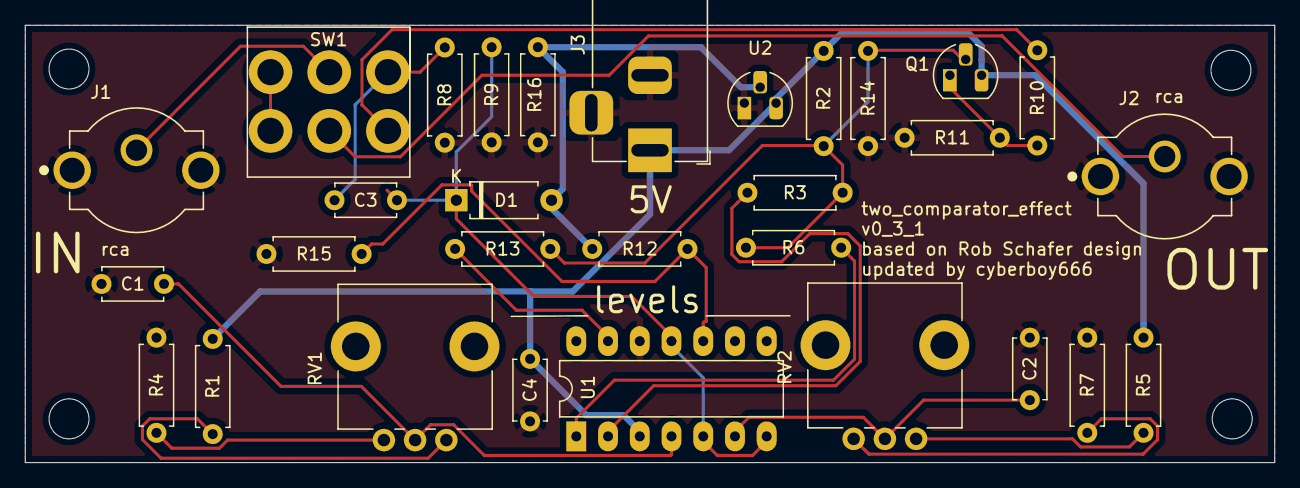
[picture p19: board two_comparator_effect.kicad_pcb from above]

Board: 2 copper layers, 100.0 x 35.0 mm, 30 parts (0 on the bottom side), 21 nets.

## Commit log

2022-01-10 migrate repo
    [two_comparator_effect.kicad_pcb, two_comparator_effect.sch]
2022-01-10 folder restructure
    [two_comparator_effect.kicad_pcb, two_comparator_effect.sch]
2022-01-19 refactor files
    [two_comparator_effect.kicad_pcb]
2022-01-19 adding csv files
    [mouser_bom.csv, tayda_bom.csv, tayda_bom_x10.csv]
2022-01-30 more refactor files
    [full_bom.csv, mouser_bom.csv, two_comparator_effect.sch]
2022-01-31 update booklet
    [two_comparator_effect.kicad_pcb]
2022-02-09 rename schamtic
    [two_comparator_effect.sch]
2022-02-22 lastest gerber
2022-02-28 update bom
    [full_bom.csv, mouser_bom.csv, tayda_bom.csv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]
2022-09-19 changed theshold resistor values
    [full_bom.csv, tayda_bom.csv, tayda_bom_10x.csv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]
2023-07-12 add panel stuff
    [back_panel-Edge_Cuts.dxf, back_panel.kicad_pcb, back_panel.kicad_sch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]
2024-05-19 add git attribute
    [two_comparator_effect.csv]
